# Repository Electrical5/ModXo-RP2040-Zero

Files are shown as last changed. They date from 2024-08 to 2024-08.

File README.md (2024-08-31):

# ModXo adapter board for RP2040-Zero / RP2040-Tiny
Unofficial board for the original Xbox modchip "[ModXo](https://github.com/Team-Resurgent/Modxo)" by Team Resurgent.

* Using the smaller (USB-C) version RP2040-Zero by WaveShare.
* Cut-out in the middle of the PCB to allow the RP2040 to lay flush / improve cooling.
* Using both universal footprints to support both SMD and THT for easier soldering / finding parts.
* Single-sided PCB for easier manufacturing.

See the [Release V0.2](https://github.com/Electrical5/ModXo-RP2040-Zero/releases/tag/V0.2) for the 'old' board.

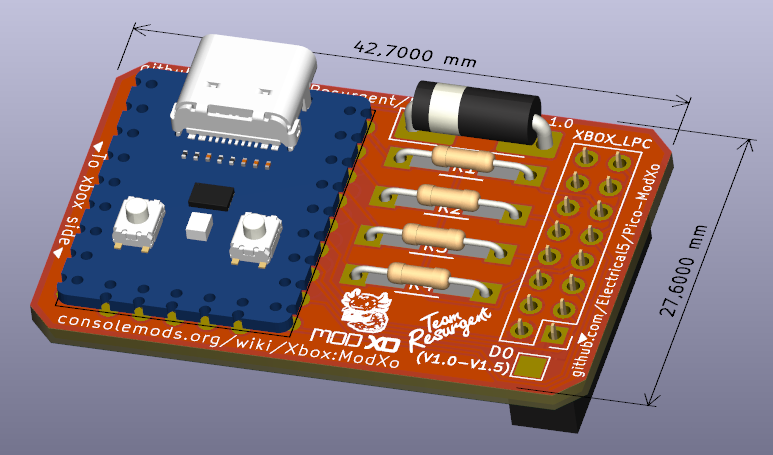
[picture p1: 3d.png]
3d


# Parts
- 4x 100Ω resistor
- 1x RP2040-Zero (WaveShare)
- Diode to protect when both PC and XBox are connected. (Optional)

# Notes
On 1.6 you will need to rebuild LPC before being able to install a modchip.
On 1.0-1.5 you will need to use D0 (solder pad on board).

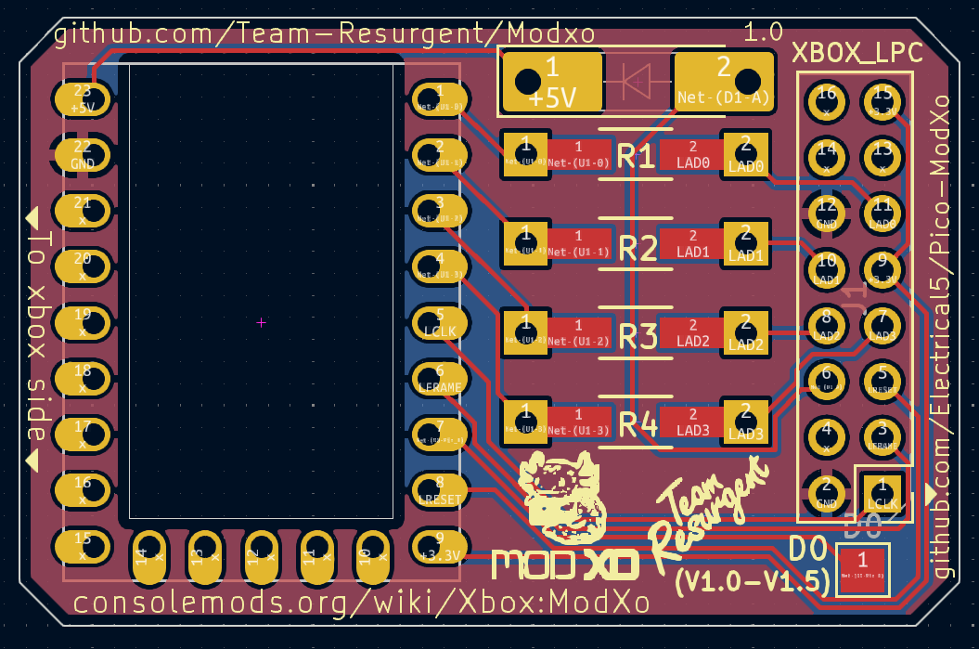
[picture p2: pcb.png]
2d


# Fully open source

The KiCad (free application) source files (full schematics!) are included, so you can add/remove components based on your preferences.

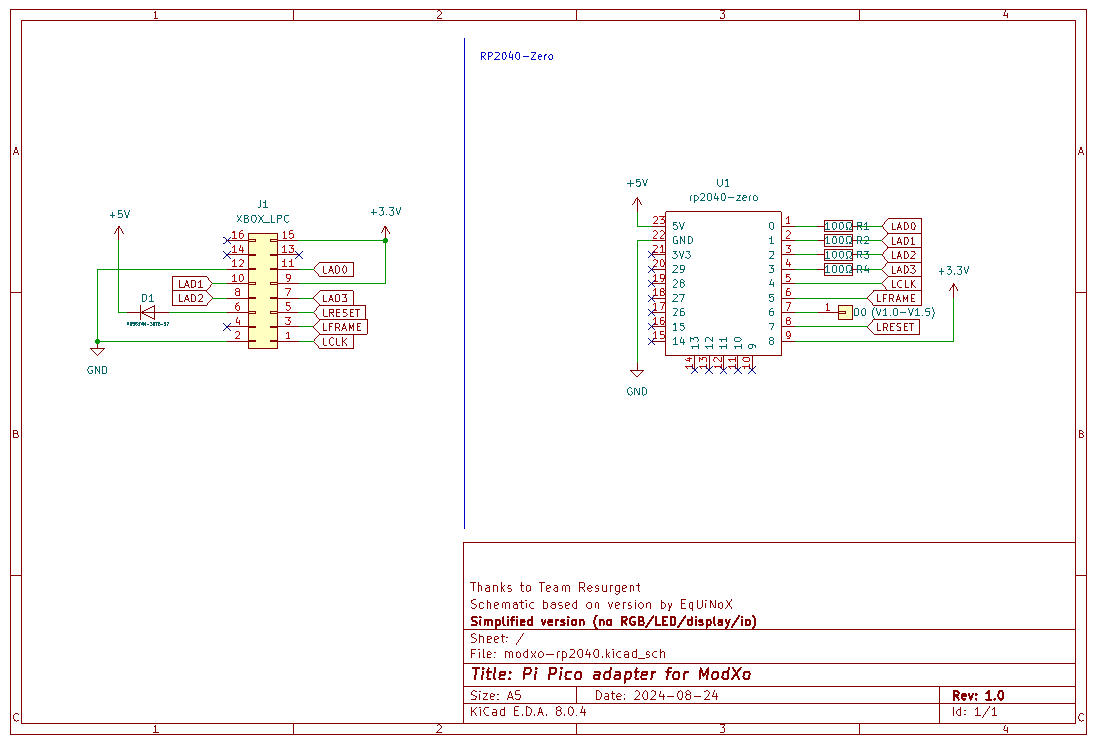
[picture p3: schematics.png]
schematics


# Cutout for RP2040-Zero

The RP2040-Zero has components on the back of the board, to allow for easier installation, there's a cutout in the board.
Though do note you can also install the RP2040-Zero using headers:

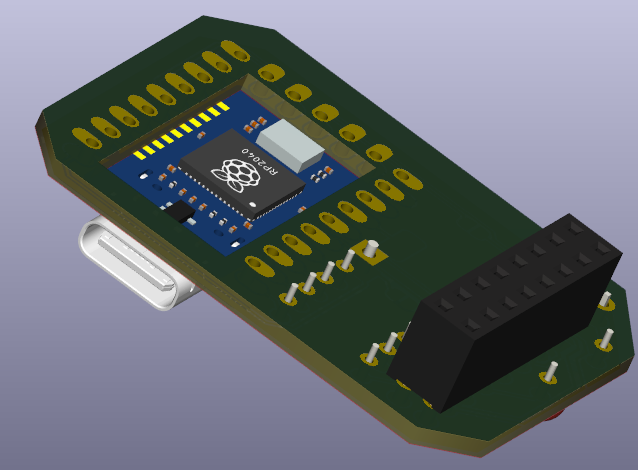
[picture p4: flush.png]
flush


# License

GNU GENERAL PUBLIC LICENSE
Version 3, 29 June 2007

You can sell this board as-is, but disclose the source.
If you sell modifications of this board (additional headers for LED strips / LCD / fan), share the modifications / source files under the same license.

# More info

https://github.com/Team-Resurgent/Modxo

https://consolemods.org/wiki/Xbox:ModXo

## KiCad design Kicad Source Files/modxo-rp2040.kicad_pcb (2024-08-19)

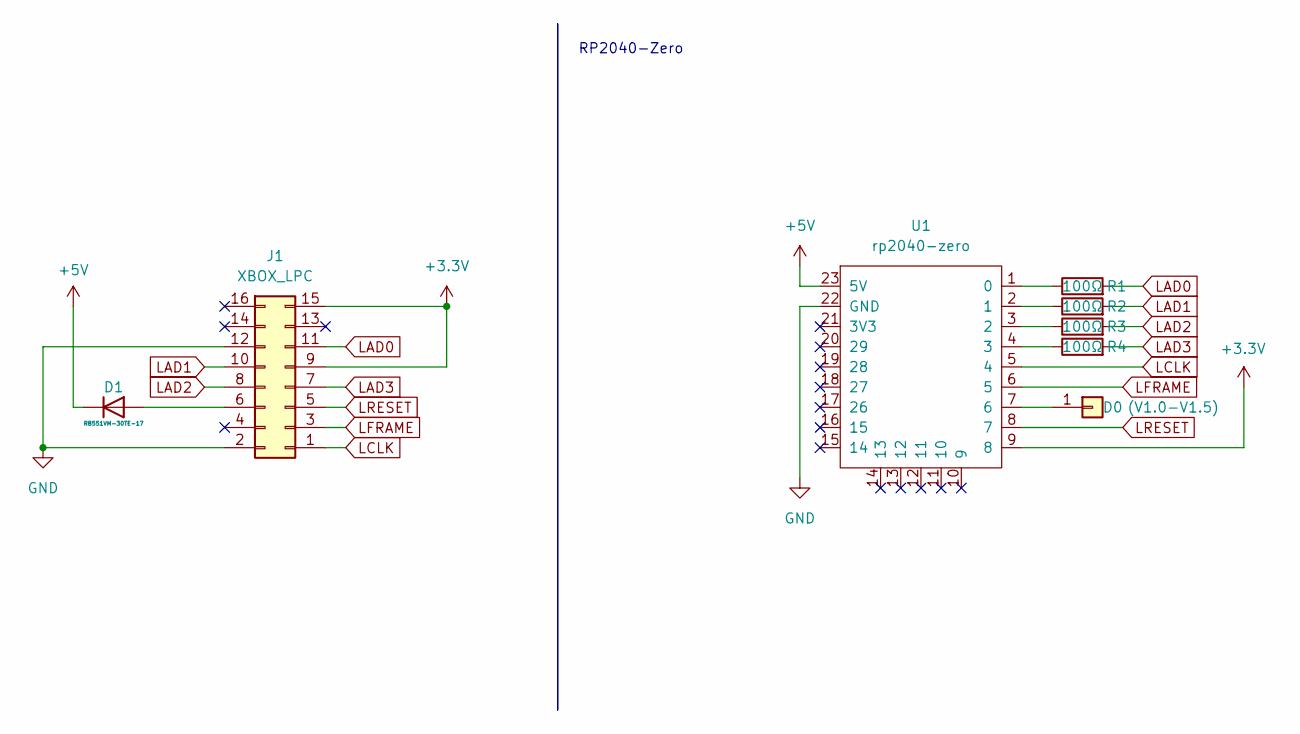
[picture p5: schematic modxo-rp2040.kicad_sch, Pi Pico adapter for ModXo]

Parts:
D0: (V1.0-V1.5); TestPoint_Pad_2.0x2.0mm
D1: RB551VM-30TE-17; D_MELF-RM10_Universal_Handsoldering
J1: XBOX_LPC; xbox_lpc
R1, R2, R3, R4: 100Ω; Resistor_SMD+THTuniversal_1206_RM10_HandSoldering
U1: rp2040-zero; rp2040-zero-tht

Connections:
+3.3V: J1.9 (3.3V), J1.15 (3.3V), U1.9 (8)
+5V: D1.1 (K), U1.23 (5V)
GND: J1.2 (GND), J1.12 (GND), U1.22 (GND)
LAD0: J1.11 (LAD0), R1.2
LAD1: J1.10 (LAD1), R2.2
LAD2: J1.8 (LAD2), R3.2
LAD3: J1.7 (LAD3), R4.2
LCLK: J1.1 (LCLK), U1.5 (4)
LFRAME: J1.3 (LFRAME#), U1.6 (5)
LRESET: J1.5 (LRESET#), U1.8 (7)
unnamed: D0.1, U1.7 (6)
unnamed: D1.2 (A), J1.6 (5V)
unnamed: R1.1, U1.1 (0)
unnamed: R2.1, U1.2 (1)
unnamed: R3.1, U1.3 (2)
unnamed: R4.1, U1.4 (3)

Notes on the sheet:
RP2040-Zero

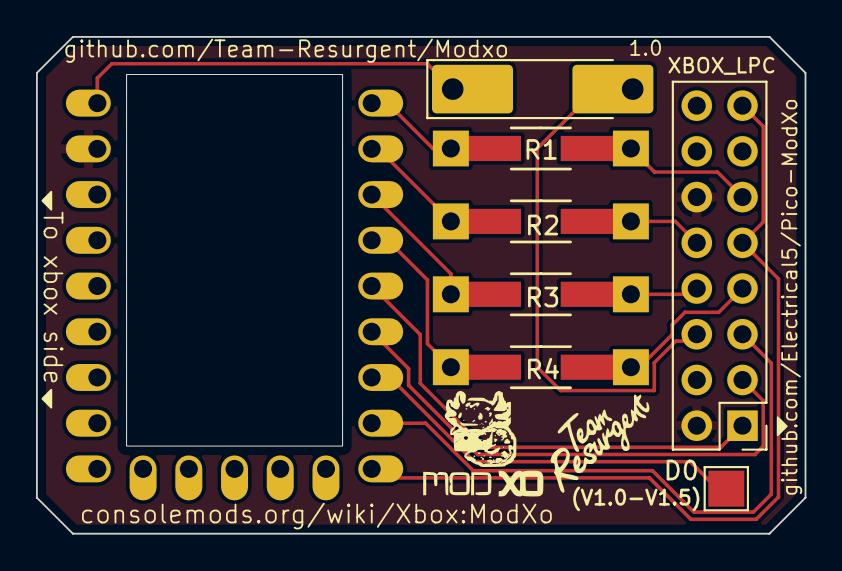
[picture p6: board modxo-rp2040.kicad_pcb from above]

Board: 2 copper layers, 42.7 x 27.6 mm, 8 parts (0 on the bottom side), 16 nets.

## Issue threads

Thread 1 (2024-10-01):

Xbox 1.4

danko79, 2024-10-01:
Hi, i have a problem with this RP2040 adapter on my Xbox 1.4 soldered only pin header in according on this schematic https://raw.githubusercontent.com/Team-Resurgent/Modxo/refs/heads/main/images/lpc_header_wiring.png

The RP2040 Zero Tiny buy on aliexpress clone boards that are not compatible? several times test when power on the console not boot no video.

For install .uf2 this tutorial for flash 3 file https://www.youtube.com/watch?v=MQKD-ZZeMD8&t=345s

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

Electrical5, 2024-10-01:
Does this RP2040-Tiny have the 'WaveShare' logo on the back?
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

Could you try installing PrometheOS and checking what color the LED lights up to when you connect it to the xbox and start up the xbox?
[RP2040 Zero Prometheos V1.4.0.zip](https://github.com/user-attachments/files/17213740/RP2040.Zero.Prometheos.V1.4.0.zip)

danko79, 2024-10-01:
Hi, assembled another one with RP2040 Zero, works fine, the problems is the RP2040 Zero Tiny. Thanks

Closed 2024-10-01.

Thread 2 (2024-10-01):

Bill of Materials

dcook101, 2024-10-01:
Hello, most of the components required look straightforward enough.
I wasn't sure what type of Diode to purchase for this adapter board?
Apologies I'm totally new to this.

Thanks

danko79, 2024-10-01:
4 pcs 100R 1/4w resitors
1 pcs diode 1N4148 optional

Electrical5, 2024-10-01:
Yes practically any diode works.
Also, the diode is only really required if you connect both the xbox and PC at the same time.

Closed 2024-10-01.

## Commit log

2024-08-03 Initial commit
    V1.0
    [ModXo-RP2040-Zero.kicad_pcb, ModXo-RP2040-Zero.kicad_sch]
2024-08-03 Added images
    [ModXo-RP2040-Zero.kicad_pcb]
2024-08-19 Added traces for V1.0
    Added traces for V1.0
    [ModXo-RP2040-Zero.kicad_pcb, pico-modxo.kicad_pcb, pico-modxo.kicad_sch]
2024-08-19 Added logos
    [modxo-rp2040.kicad_pcb, modxo-rp2040.kicad_sch]
2024-08-19 V1.0 pictures and gerber zip
    V1.0 pictures and gerber zip
    [modxo-rp2040.kicad_pcb]

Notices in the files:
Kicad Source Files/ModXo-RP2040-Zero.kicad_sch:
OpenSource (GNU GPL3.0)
